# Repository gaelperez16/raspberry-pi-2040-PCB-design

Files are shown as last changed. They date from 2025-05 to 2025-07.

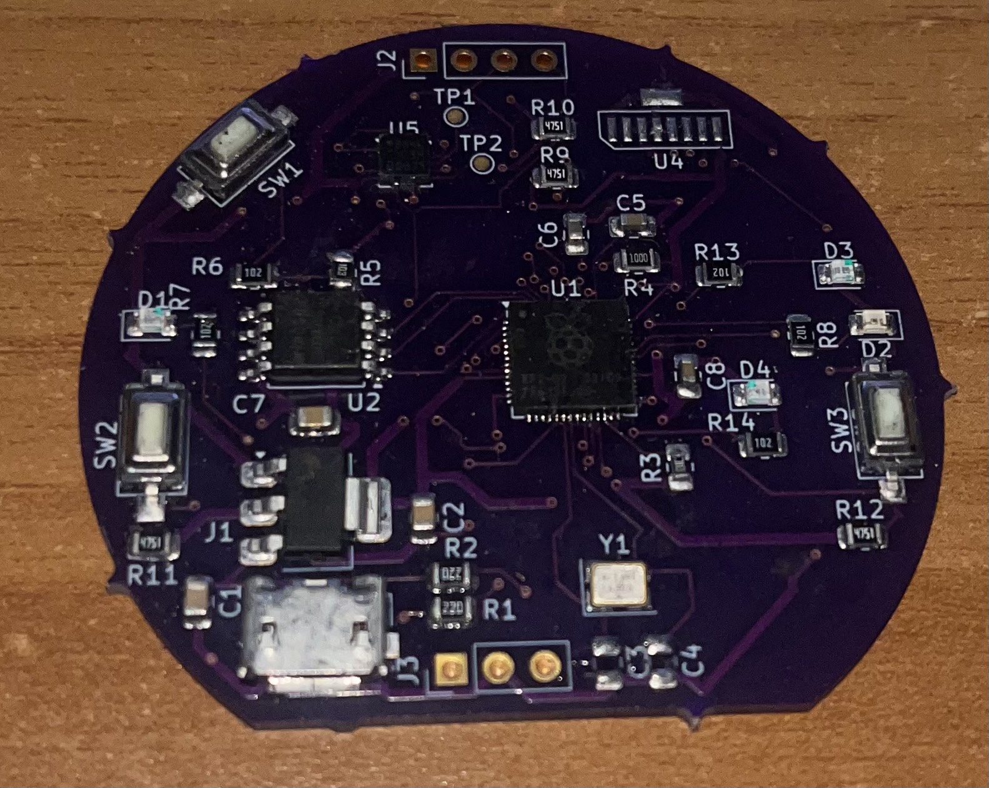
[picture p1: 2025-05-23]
RP-2040 screenshots/Fully soldered +Tested via Linux commands.jpg

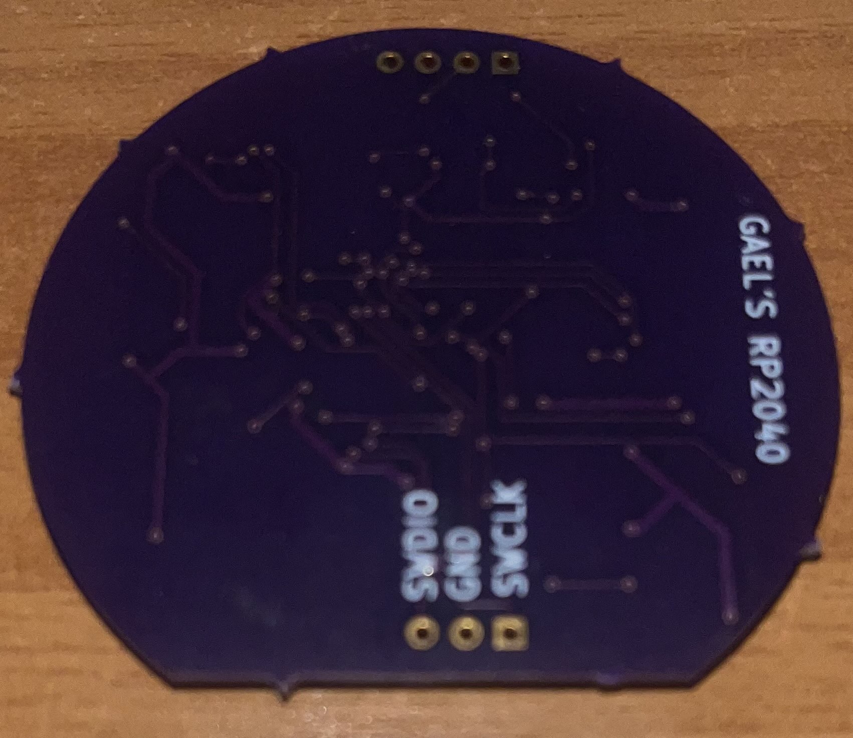
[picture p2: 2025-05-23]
RP-2040 screenshots/Fully soldered back.jpg

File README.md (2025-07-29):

# GAEL'S RP2040 Board

## Overview

This repository contains the complete KiCad project, schematic, PCB layout, 3D renders, and images of the final assembled board for **Gael’s custom RP2040 development board**. It includes a USB-B power interface, LIS3DH accelerometer for motion sensing, push buttons, LEDs, and header pins for debugging and expansion. 

Designed to be compact and circular, this board is suitable for embedded applications, including wearable tech and motion-aware devices.

---

## Features

- **Microcontroller:** Raspberry Pi RP2040
- **Accelerometer:** STMicroelectronics LIS3DH (3-axis, I2C)
- **Debug Header:** SWDIO, SWCLK
- **Buttons:** 3 tactile push buttons
- **LEDs:** 4 indicators
- **USB:** USB Micro-B for power and programming
- **Power Supply:** 3.3V regulated via AMS1117
- **Clock:** 12 MHz crystal oscillator
- **Form Factor:** Custom round PCB

---

## Hardware Components

| Component | Description | Datasheet / Link |
|---|---|---|
| [RP2040](https://www.raspberrypi.com/documentation/microcontrollers/rp2040.html) | Dual-core ARM Cortex M0+ microcontroller | [PDF Datasheet](https://datasheets.raspberrypi.com/rp2040/rp2040-datasheet.pdf) |
| [LIS3DH](https://www.st.com/en/mems-and-sensors/lis3dh.html) | Low-power 3-axis accelerometer | [PDF Datasheet](https://www.st.com/resource/en/datasheet/lis3dh.pdf) |
| [AMS1117-3.3](https://www.advanced-monolithic.com/pdf/ds1117.pdf) | 3.3V Linear Voltage Regulator | [PDF Datasheet]) |
| USB Micro-B Connector | USB interface for power and programming | [Example Part](https://www.sparkfun.com/products/9966) |
| 12 MHz Crystal Oscillator | Provides clock source for RP2040 | [Typical Part](https://www.digikey.com/en/products/detail/ecs-inc/ECS-120-12-33A-EN/3083686) |

---

## Project Structure

```bash
📁 rp2040-board/
├── hardware/
│   ├── RP2040.kicad_sch        # KiCad schematic
│   ├── RP2040.kicad_pcb        # KiCad PCB layout
│   ├── gerbers/                # Gerber fabrication files
├── images/
│   ├── 3D_viewer_top_side.jpg
│   ├── 3D_viewer_bottom_side.jpg
│   ├── Front_and_Back_Layout.jpg
│   ├── Fully_soldered.jpg
│   ├── Fully_soldered_back.jpg
├── README.md                   # Project documentation

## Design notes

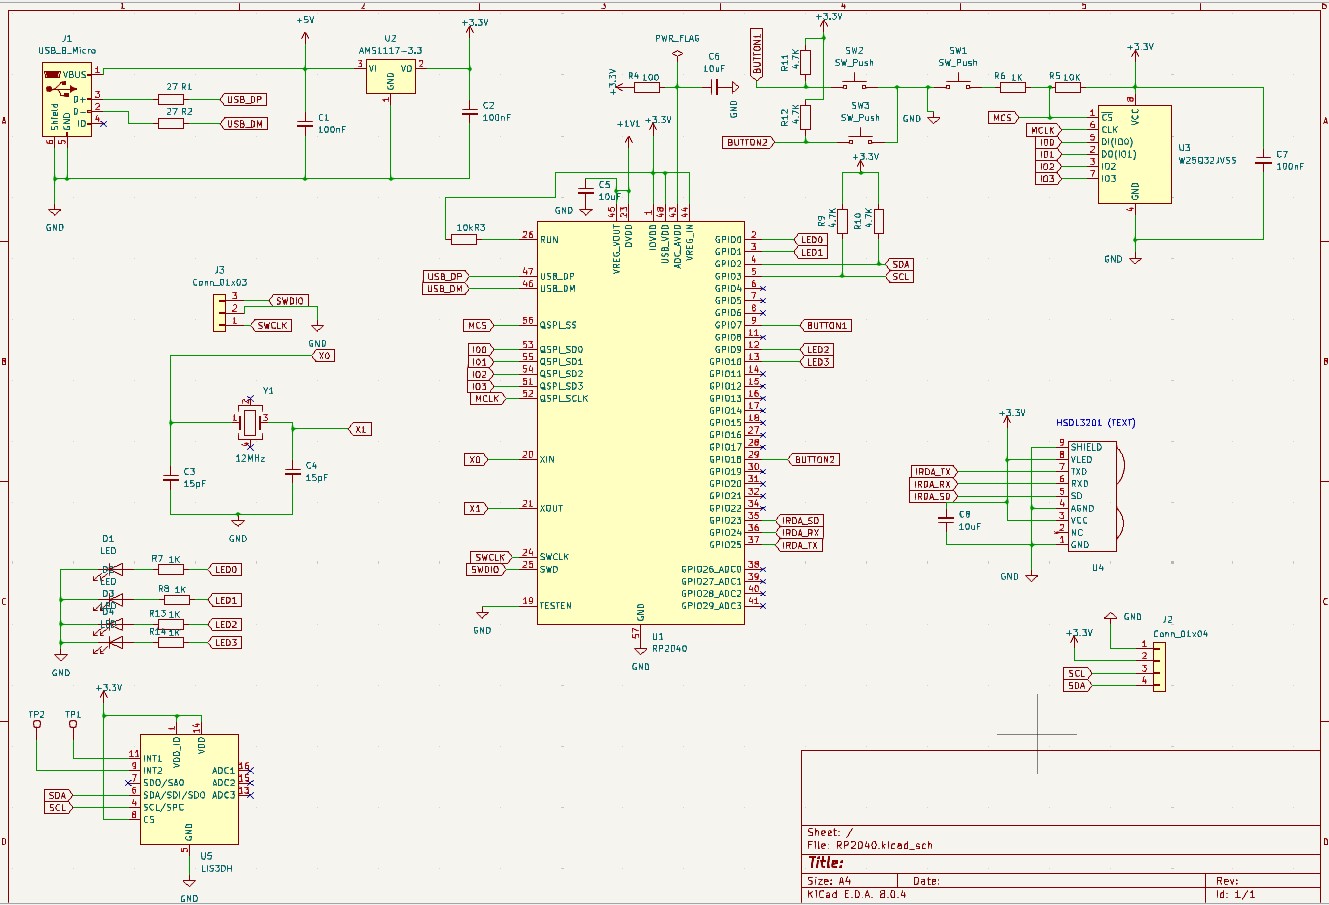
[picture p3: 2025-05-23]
RP-2040 screenshots/Full Schematic.jpg

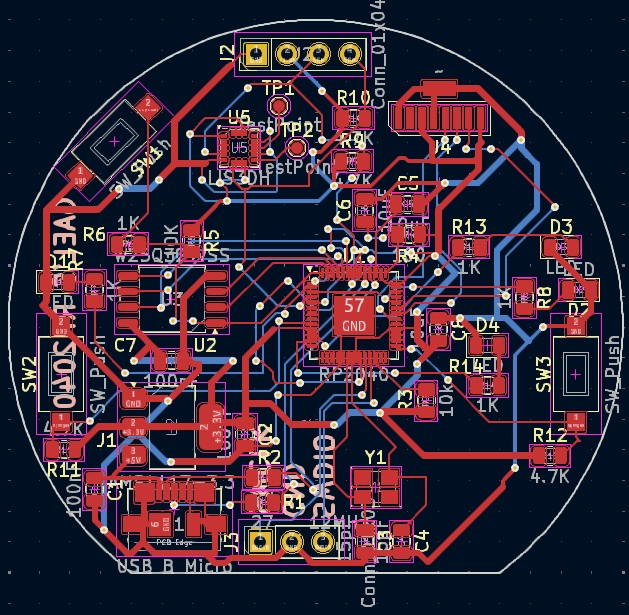
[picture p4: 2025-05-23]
RP-2040 screenshots/Front and Back Layout.jpg

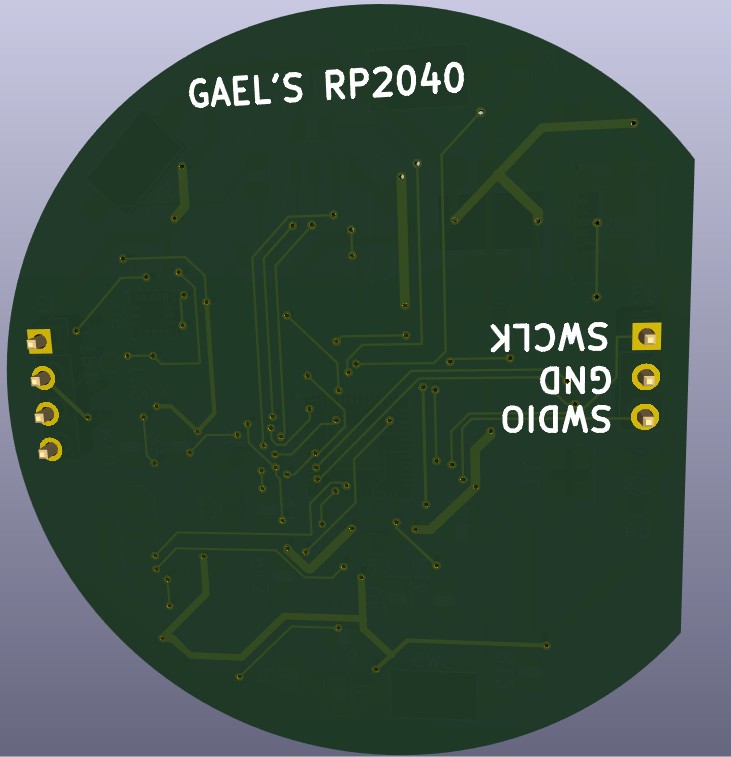
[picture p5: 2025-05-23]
RP-2040 screenshots/3D viewer bottom side.jpg

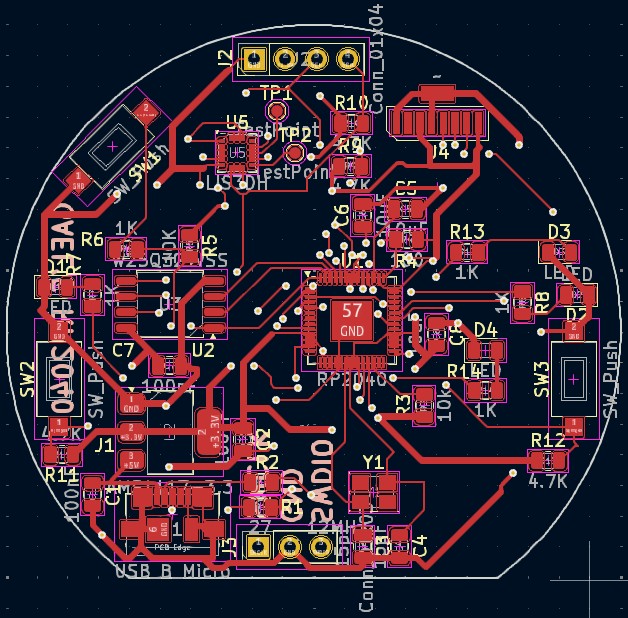
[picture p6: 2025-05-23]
RP-2040 screenshots/Front Layout.jpg

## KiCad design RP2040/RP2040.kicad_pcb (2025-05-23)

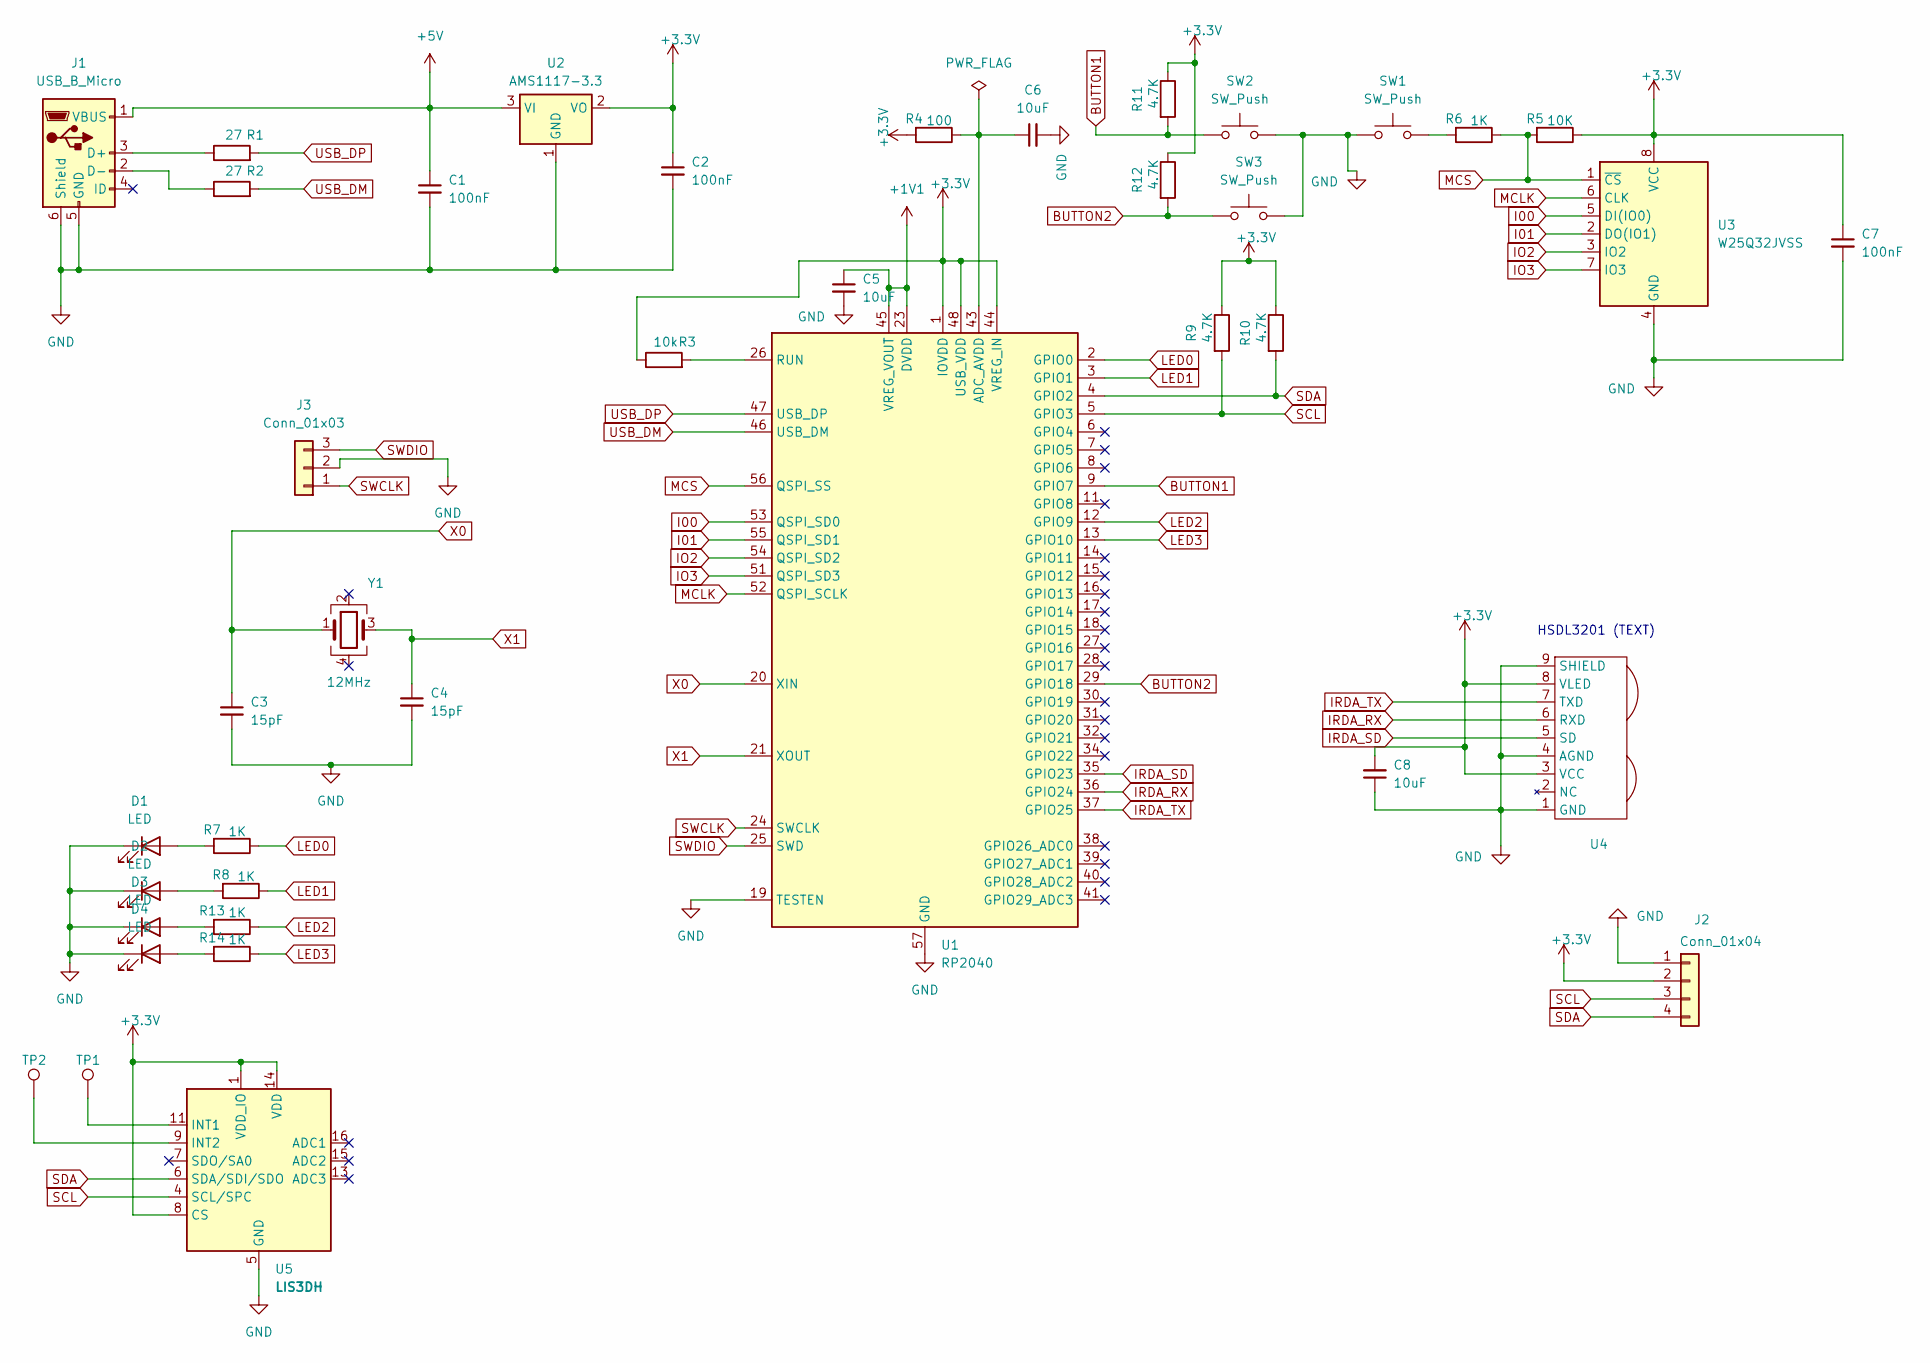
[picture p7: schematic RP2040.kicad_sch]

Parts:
C1, C2, C7: 100nF; C_0805_2012Metric
C3, C4: 15pF; C_0805_2012Metric
C5, C6, C8: 10uF; C_0805_2012Metric
D1, D2, D3, D4: LED; LED_0805_2012Metric
J1: USB_B_Micro; USB_Micro-B_Molex_47346-0001
J2: Conn_01x04; PinHeader_1x04_P2.54mm_Vertical
J3: Conn_01x03; PinHeader_1x03_P2.54mm_Vertical
R1, R2: 27; R_0805_2012Metric
R3: 10k; R_0805_2012Metric
R4: 100; R_0805_2012Metric
R5: 10K; R_0805_2012Metric
R6, R7, R8, R13, R14: 1K; R_0805_2012Metric
R9, R10, R11, R12: 4.7K; R_0805_2012Metric
SW1, SW2, SW3: SW_Push; SW_SPST_CK_RS282G05A3
TP1, TP2: TestPoint; TestPoint_Pad_D1.0mm
U1: RP2040; QFN-56-1EP_7x7mm_P0.4mm_EP3.2x3.2mm
U2: AMS1117-3.3; SOT-223-3_TabPin2
U3: W25Q32JVSS; SOIC-8_5.23x5.23mm_P1.27mm
U4: HSDL3201
U5: LIS3DH; LGA-16_3x3mm_P0.5mm_LayoutBorder3x5y
Y1: 12MHz; Crystal_SMD_SeikoEpson_FA238-4Pin_3.2x2.5mm

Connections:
+1V1: C5.1, U1.23 (DVDD), U1.45 (VREG_VOUT), U1.50 (DVDD)
+3.3V: C2.1, C7.1, C8.2, J2.2, R3.1, R4.2, R5.1, R9.1, R10.1, R11.1, R12.1, U1.1 (IOVDD), U1.10 (IOVDD), U1.22 (IOVDD), U1.33 (IOVDD), U1.42 (IOVDD), U1.44 (VREG_IN), U1.48 (USB_VDD), U1.49 (IOVDD), U2.2 (VO), U3.8 (VCC), U4.3 (VCC), U4.8 (VLED), U5.1 (VDD_IO), U5.8 (CS), U5.14 (VDD)
+5V: C1.1, J1.1 (VBUS), U2.3 (VI)
BUTTON1: R11.2, SW2.1, U1.9 (GPIO7)
BUTTON2: R12.2, SW3.1, U1.29 (GPIO18)
GND: C1.2, C2.2, C3.2, C4.2, C5.2, C6.2, C7.2, C8.1, D1.1 (K), D2.1 (K), D3.1 (K), D4.1 (K), J1.5 (GND), J1.6 (Shield), J2.1, J3.2, SW1.1, SW2.2, SW3.2, U1.19 (TESTEN), U1.57 (GND), U2.1 (GND), U3.4 (GND), U4.1 (GND), U4.4 (AGND), U4.9 (SHIELD), U5.5 (GND), U5.10 (GND), U5.12 (GND)
I00: U1.53 (QSPI_SD0), U3.5 (DI(IO0))
I01: U1.55 (QSPI_SD1), U3.2 (DO(IO1))
IO2: U1.54 (QSPI_SD2), U3.3 (IO2)
IO3: U1.51 (QSPI_SD3), U3.7 (IO3)
IRDA_RX: U1.36 (GPIO24), U4.6 (RXD)
IRDA_SD: U1.35 (GPIO23), U4.5 (SD)
IRDA_TX: U1.37 (GPIO25), U4.7 (TXD)
LED0: R7.1, U1.2 (GPIO0)
LED1: R8.1, U1.3 (GPIO1)
LED2: R13.1, U1.12 (GPIO9)
LED3: R14.1, U1.13 (GPIO10)
MCLK: U1.52 (QSPI_SCLK), U3.6 (CLK)
MCS: R5.2, R6.1, U1.56 (QSPI_SS), U3.1 (~CS)
unnamed: D1.2 (A), R7.2
unnamed: D2.2 (A), R8.2
unnamed: D3.2 (A), R13.2
unnamed: D4.2 (A), R14.2
unnamed: J1.3 (D+), R1.1
unnamed: J1.2 (D-), R2.1
unnamed: R6.2, SW1.2
unnamed: C6.1, R4.1, U1.43 (ADC_AVDD)
unnamed: R3.2, U1.26 (RUN)
unnamed: TP1.1, U5.11 (INT1)
unnamed: TP2.1, U5.9 (INT2)
SCL: J2.3, R9.2, U1.5 (GPIO3), U5.4 (SCL/SPC)
SDA: J2.4, R10.2, U1.4 (GPIO2), U5.6 (SDA/SDI/SDO)
SWCLK: J3.1, U1.24 (SWCLK)
SWDIO: J3.3, U1.25 (SWD)
USB_DM: R2.2, U1.46 (USB_DM)
USB_DP: R1.2, U1.47 (USB_DP)
X0: C3.1, U1.20 (XIN), Y1.1
X1: C4.1, U1.21 (XOUT), Y1.3

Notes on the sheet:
HSDL3201 (TEXT)

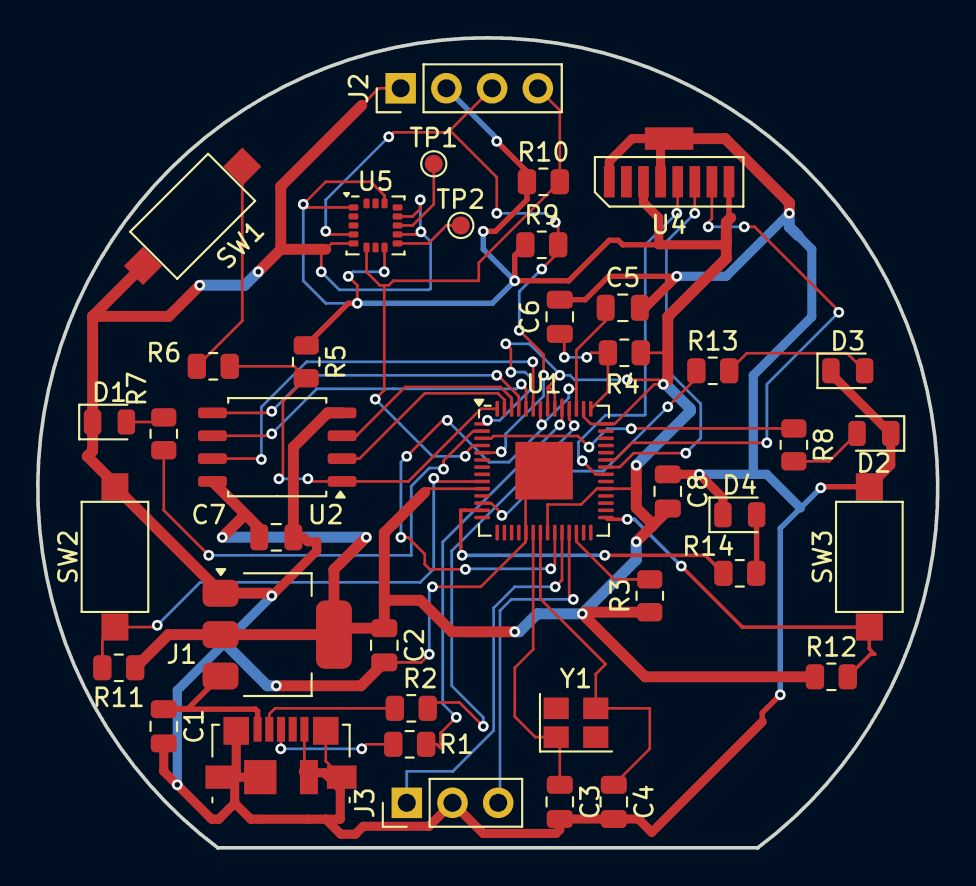
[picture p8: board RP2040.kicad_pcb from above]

Board: 2 copper layers, 50.0 x 45.0 mm, 40 parts (0 on the bottom side), 38 nets.
